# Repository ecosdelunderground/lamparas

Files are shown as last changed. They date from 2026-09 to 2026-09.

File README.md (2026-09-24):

# Ciudadela / Starlit Stag — lámpara imprimible

Del OBJ de Meshy a **tres piezas** que se montan con cinco tornillos. La silueta y
la piedra del marco son **las del OBJ original**. El nicho (escalón, corona,
pozo) está **redibujado según la Ciudadela de Jaca** (`ciudadela.py`): polígonos
limpios y simétricos, planos de verdad, nada cortado contra las facetas de Meshy.

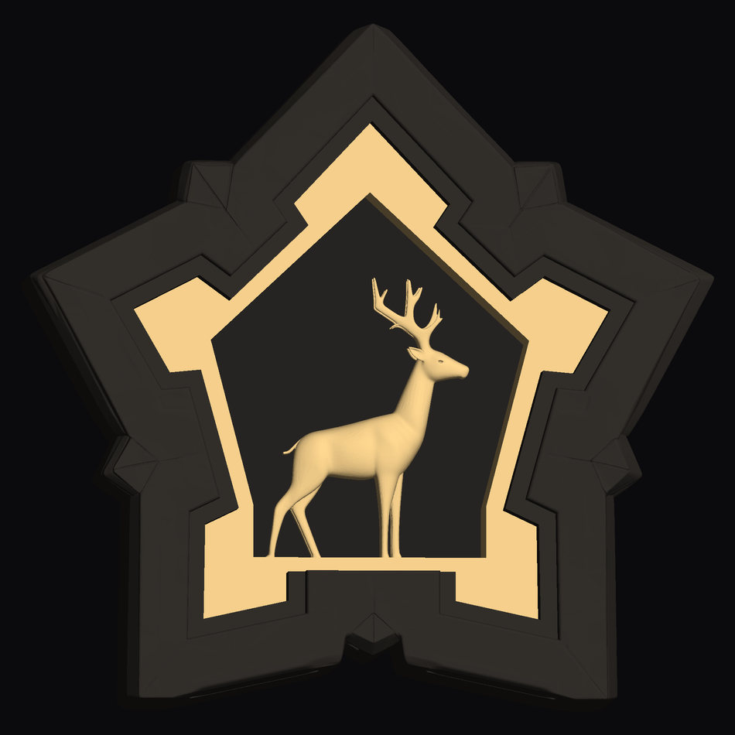
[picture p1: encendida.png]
encendida


## Las tres paredes

| pared | pieza | material |
|---|---|---|
| exterior, el marco de la estrella | `1_piedra` | opaco |
| **la iluminada**: la corona que rodea la boca del nicho | `2_luz` | **translúcido** |
| **el escalón interno** que baja hasta el fondo | `2_luz` | **translúcido** |
| la de detrás del ciervo | `3_tapa` (pedestal) | opaco |
| el ciervo, en relieve | `2_luz` | **translúcido** |

La pared iluminada es la corona plana a Z = +10,90 (**3 885 mm²**). El escalón
interno son las cinco paredes del pozo, 23,9 mm de caída. El fondo del nicho no
emite: son **13,4 mm de opaco macizo**, y va montado en la tapa.

### El trazado de la Ciudadela (`ciudadela.py`)

Simétrico respecto a X = 0, de fuera hacia dentro:

- **Marco de 17 mm constante** en todas las caras de los baluartes (silueta → W2).
- **Escalón de 5 mm constante** (W2 → borde de la corona), plano único a Z 21,34.
- Entre baluartes, cortina con orejón a cada lado; **entrantes a 100°**.
- Puntas laterales con las dos caras iguales (29,8 mm).
- **Pozo**: pentágono simétrico con los lados de abajo verticales, para
  enmarcar al ciervo; el ciervo va **4,9 mm a la derecha** para quedar centrado.
- Contorno interior: la franja de terraza junto a la pared (8 mm) se rehace a la
  altura de la terraza buena, con un **canto redondo de 1 mm** arriba de la pared.
- Rombo de la punta de abajo: **copia de la malla del rombo lateral**, llevada a
  la punta de abajo y reflejada (simétrico).
- Canto de fuera de las dos caras de abajo (en Meshy ondulaba): perfil medio
  barrido recto a lo largo de la cara.
- Todas las costuras con Meshy se cruzan en ángulo suave: sin escalón.

## Las tres piezas

| | filamento | tamaño | volumen |
|---|---|---|---|
| `1_piedra` | opaco, acabado piedra | 200 × 198 × 55 mm | 752 cm³ |
| `2_luz` | **translúcido** | 139 × 145 × 37 mm | 78 cm³ |
| `3_tapa` | opaco | 166 × 171 × 16 mm | 138 cm³ |

`2_luz` es **una sola pieza**: corona + escalón interno + ciervo + una **falda
exterior** que baja desde el borde de la corona hasta la tapa. Entre el tubo y la
falda, un **pasillo de luz de 5 mm que da la vuelta entera** al tubo (también bajo
el suelo del ciervo), sin macizos que hagan sombra; en las puntas se ensancha. Donde
no cabe bajo la corona, la falda se sale de ella hasta 1,9 mm por detrás, escondida
dentro de la piedra. La falda le da a la corona en qué apoyarse y sitúa la pieza en
el hueco.

## El ciervo

Ya no flota con un tallo por detrás. Es un **relieve de 15 mm** que sale de la
pared del fondo: se recula 10,9 mm y se queda pegado a ella, conservando su
contorno exacto y los 15 mm delanteros de su modelado original. Por detrás no
queda nada: el hueco del ciervo desemboca directamente en un agujero con su
silueta (metida 2,5 mm, así que no se ve) en el pedestal de la tapa, y ahí es
donde va su trozo de tira LED.

## Medidas

| | |
|---|---|
| Estrella | 200 × 198 mm |
| Grosor | 55,1 mm + 3 mm de tapa = **58,1 mm** |
| Nicho | 23,9 mm de profundidad |
| Fondo del nicho | **13,4 mm de opaco** |
| Relieve del ciervo | 15 mm |
| Pasillo de luz | 5 mm alrededor de todo el tubo |
| Paredes translúcidas | 2,0 mm mínimo |

## Impresión

Las tres salen **en la orientación en la que están exportadas**, cara plana abajo
y todas las cavidades abriendo hacia arriba. Piedra y tapa, **sin soportes**.
La luz, **con soportes solo debajo del ciervo**: su relieve empieza 13,4 mm por
encima de la cama (8 islas entre Z −13,0 y −3,4). Los soportes tocan el lomo
trasero, que va contra el fondo y no se ve. Lo demás de la luz se puentea solo:
la primera capa de la corona es un puente de 15,1 mm como mucho (en las puntas;
revisa los ajustes de puentes del laminador).

- Boquilla 0,4 · capa 0,2 · **3 perímetros**.
- Piedra: relleno 10–15 %. Huella de 200 × 198 mm, comprueba que te cabe.
- Luz: **10 % de giroide y 3 perímetros** (0 % dejaría la corona sin sobre qué
  apoyar las capas de arriba).
- Tapa: 15 %.

La trasera de la estrella la he **aplanado 0,5 mm** para quitarle la textura de
Meshy: agarra la primera capa y la tapa asienta plana.

## Montaje

1. Mete `2_luz` **por detrás**, empujando hacia delante hasta que la corona
   asiente en su rebaje.
2. Pega la tira LED dentro de la caja de `2_luz`, sobre la tapa, y un trozo justo
   debajo del agujero del ciervo. Pasa el cable por la muesca del espigo.
3. Atornilla `3_tapa`: **5 × M3 × 10 autorroscantes de cabeza avellanada**
   (el avellanado de 90° abre hacia la cara de fuera y la cabeza queda
   enrasada), a taladros de Ø2,7 y 8 mm de fondo. Su pedestal es el fondo del nicho y, al apretar, deja la
   pieza de luz cogida contra su rebaje: no hace falta pegamento.
4. El cable baja por el canal de la trasera y sale por la muesca de entre los dos
   pies, a ras de mesa.

Comprobado moviendo cada pieza por **todo el recorrido** de montaje (1, 2, 4, 8,
16, 30 y 50 mm), no solo en la posición final: 0 mm³ de choque.

## Ficheros

```
preparar.py      genera las tres piezas desde el OBJ (parámetros arriba del todo)
ciudadela.py     trazado del nicho (W2, escalón, pozo), fijado como diseño
verificar.py     50 comprobaciones + renders
geo.py           secciones horizontales en coordenadas mundo
render.py        rasterizador para los renders
1_piedra / 2_luz / 3_tapa   .stl y .ply
montada.3mf      las tres en su sitio, para mirarlo antes de laminar
```

## Comprobado (50/50)

- Las tres piezas cerradas, de un solo trozo, sin triángulos degenerados ni
  pellizcos (también los .stl), y sin lengüetas o rendijas de menos de 0,8 mm
  en lo construido (en la piedra rehecha solo quedan las ranuras del diseño).
- Solape entre piezas: 0,00 mm³.
- Silueta exterior intacta fuera de lo rehecho (0,019 mm); marco visto: 0 de
  1 380 puntos desviados más de 0,3 mm fuera de lo rehecho a propósito.
- Detrás del fondo del nicho: **100 % opaco**, 0 % translúcido.
- Corona: un solo plano (±0,0000 mm) y translúcida en toda su planta.
- Pared mínima: 2,0 mm en la pieza de luz, 1,16 mm en el ciervo.
- Mínimo 16,2 mm de piedra entre el pasillo de luz y el exterior.
- Recorrido de montaje completo sin choques, pieza a pieza.
- Voladizos capa a capa: puente de 4,0 mm en la piedra, 15,1 mm en la luz,
  0 en la tapa; las únicas islas son las 8 bajo el ciervo (con soporte).

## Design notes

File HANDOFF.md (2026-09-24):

# Handoff — lámpara Ciudadela / Starlit Stag

Pega esto en una sesión nueva para continuar.

---

Estoy preparando para imprimir en 3D una lámpara a partir de un OBJ de Meshy AI.
El proyecto vive en `C:\Users\sergi\Documents\claudeproject\estrella-meshy`.
Lee primero el `README.md` y `preparar.py` de esa carpeta.

**Entorno**: Python de sistema en
`C:/Users/sergi/AppData/Local/Programs/Python/Python313/python.exe`, con trimesh,
shapely, manifold3d, scipy, matplotlib, PIL, rtree. El motor de booleanas es
`manifold`. El OBJ original está en
`C:/Users/sergi/Downloads/Meshy_AI_Starlit_Stag_0923134854_generate_obj/Meshy_AI_Starlit_Stag_0923134854_generate_obj/Meshy_AI_Starlit_Stag_0923134854_generate.obj`.
No modifiques el OBJ; todo se genera desde él con `preparar.py`.

## Qué es

Estrella de 5 puntas de 200 × 198 × 58 mm con un nicho pentagonal y un ciervo
dentro. Se imprime en **tres piezas** y se monta con 5 tornillos M3:

- `1_piedra` (filamento opaco, acabado piedra): el marco de la estrella.
- `2_luz` (filamento **translúcido**): UNA sola pieza = la corona iluminada que
  rodea la boca del nicho + el escalón interno (la pared del pozo) + el ciervo en
  relieve + una **falda exterior** oculta dentro de la piedra que hace que la
  pieza se imprima sin soportes y forma la caja donde va la tira LED.
- `3_tapa` (opaco): cierra por detrás, lleva los tornillos y el canal del cable, y
  **lleva montado el fondo del nicho** (la pared de detrás del ciervo) como un
  pedestal de 13,4 mm.

## La regla de la luz (esto costó cinco rondas, no te la saltes)

Hay **tres paredes** en el nicho. Solo se encienden dos de ellas y el ciervo:

| pared | pieza | ¿emite? |
|---|---|---|
| marco exterior de la estrella | `1_piedra` | **NO** |
| **la corona iluminada** (la franja plana a Z ≈ +11 que rodea la boca, 7–9 mm de ancho vista de frente) | `2_luz` | **SÍ** |
| **el escalón interno** (las paredes del pozo, 24 mm de caída) | `2_luz` | **SÍ** |
| el fondo, detrás del ciervo | pedestal de `3_tapa` | **NO** |
| el ciervo | `2_luz` | **SÍ** |

El ciervo es un **relieve de 15 mm** pegado al fondo: se recula 10,9 mm respecto
al OBJ y se corta en el plano del fondo. No lleva tallo ni hueco por detrás; la
luz le entra por un agujero con su silueta (metida 2,5 mm, así no se ve) en el
pedestal de la tapa. Las pezuñas se hunden 4 mm en el suelo del pozo para que el
relieve quede soldado a la pieza y no salga suelto.

## Cotas y decisiones ya cerradas

- Escala: 200 mm de ancho → 105,2085 mm por unidad del OBJ.
- Planos: trasera aplanada `Z=-26,41` · fondo del nicho `Z=-12,99` · cara de la
  corona `Z=+10,90` · junta corona/tubo `Z=+7,40` · frente `Z=+28,69`.
- Pared translúcida 2,0 mm, falda 2,0 mm, holgura única 0,2 mm, corona 3,5 mm.
- Orientación de impresión = la de exportación: cara plana en la cama, cavidades
  hacia arriba, **sin soportes**.
- La pieza `2_luz` entra **por detrás** (el marco se mete hacia dentro por abajo y
  no cabe por delante). La tapa también por detrás. Verificado desplazando cada
  pieza 1/2/4/8/16/30/50 mm e intersecando, no solo en la posición final.
- La trasera de la estrella se aplana 0,5 mm para quitarle la textura de Meshy.

## Dónde estoy ahora mismo (a medias)

Sergi vio las piezas en el laminador y **rechazó las costuras**: bordes en sierra,
lengüetas finas y ondulaciones, porque yo estaba cortando todas las caras de
encaje contra la malla facetada de Meshy. Medido: la cara de la corona iba de
Z +6,25 a +20,80 en vez de ser un plano, y las piezas llevaban 4 324 y 12 563
triángulos por debajo de 0,001 mm².

Acordamos con él: **nada que encaje se corta contra la malla**. Todo sale de dos
polígonos limpios (lados rectos, esquinas vivas) y dos planos de verdad. Eligió
expresamente «contornos limpios sin tocar la forma», **no** simetrizar (medí que
simetrizar movería el pozo 6,4 mm y la estrella 7,7 mm, y se lo dije).

`preparar.py` ya está reescrito con ese criterio y **corre entero**. Última salida:

```
POZO:   1467 vertices -> 16 lados rectos, desviacion max 1.03 mm, area 7171 mm2
CORONA: 6419 vertices -> 37 lados rectos, area 3398 mm2, ancho medio 7.5 mm
(la falda pide 5822 mm2 por fuera del escalon del marco)
piedra: pulido 235042 -> 235042 caras, 484 astillas, cerrada=True   754.8 cm3
luz:    la limpieza abria la malla, se deja como estaba              80.4 cm3
tapa:   la limpieza abria la malla, se deja como estaba             137.5 cm3
```

### Lo que queda por hacer

1. **`verificar.py` está desactualizado y no arranca**: espera el `cotas.npy` y el
   `contornos.wkt` del diseño anterior. Ahora `preparar.py` escribe
   `cotas = [S, Z_TRASERA, Z_SUELO, Z_CORONA, Z_JUNTA, Z_FRENTE, OFF_LUZ,
   OFF_PIEDRA, TAPA_ESP, CIERVO_RELIEVE, HOLGURA, FALDA]` y
   `contornos.wkt = SIL_CIERVO, POZO, AEX, CORONA`. Hay que adaptarlo y volver a
   pasar las comprobaciones (la versión anterior sacaba 24/24).
2. **`pulir()` no consigue limpiar `2_luz` ni `3_tapa`**: al fusionar vértices la
   malla se abre, así que se queda como estaba. Hay que resolverlo de verdad
   (fusión por distancia con tolerancia, o rehacer esas piezas para que no salgan
   astillas de las booleanas). Es justo lo que Sergi quiere arreglado.
3. **Verificar que la falda no muerde el escalón visible del marco**: el log dice
   que pide 5 822 mm² por fuera de la corona. Hay que mirarlo en render y, si se
   come marco visible, estrechar la falda o recortarla ahí.
4. **Renderizar y enseñárselo**: no he mirado todavía la versión limpia. Usa
   `render.py` (rasterizador propio) y compara con la versión anterior.
5. Actualizar el `README.md` con las cotas nuevas cuando esté cerrado.

## Sesión del 24-09 (nube): estado

El OBJ está en el repo como `meshy.obj`; `preparar.py` y `verificar.py` lo
buscan ahí primero. Piezas regeneradas. `verificar.py`: **40/43**.

Decisiones de Sergi (24-09):
- **Falda, opción B**: se deja la franja de corona que recorta el marco (bloque
  de abajo y esquina de la roca) para verlo impreso. Si no gusta, opción A:
  sin corona donde el original no la tiene, placa escondida bajo el marco.
- **Soportes solo bajo el ciervo** en la pieza de luz (su relieve empieza en el
  aire en la orientación de impresión). Descartado el apoyo oculto en el pedestal.

Hecho:
- `pulir()`: para si la booleana deja pellizcos (fallo de diseño) y colapsa
  astillas con `Manifold.simplify` (0,001 mm; la luz 0,01 mm, que cierra los
  pliegues de vacío < 0,01 mm que deja la erosión dentro del ciervo).
- Tapa: el avellanado estaba al revés y su cono tocaba el taladro en un círculo.
- Luz: boca trasera del ciervo dentro de su base real (el prisma de la silueta
  cortaba el lomo casi horizontal y pellizcaba); pezuñas prolongadas en recto
  hasta media pared del tubo (antes: muñones fantasma y asomaban a la caja).
- POZO: la envolvente se muestrea solo hasta la junta. Antes llegaba a Z +9,4 y
  metía en el pozo un rellano de la corona (esquina de la roca, Z ≈ +9), creando
  un pocillo iluminado de 24 mm que el original no tiene. Desvío al original:
  19,4 → 1,74 mm.
- `verificar.py`: malla limpia, regla de la luz, falda, sección 4 separando lo
  aceptado, recorrido fino, e islas en el aire (la de antes no las veía).

- Malla perfecta: `sanear()` en `pulir()` quita los triángulos degenerados
  (colapsa lados < 0,01 mm con condición de enlace, voltea agujas) y exige 0.
  `verificar.py` comprueba también los .stl.
- `render.py` con z-buffer: el algoritmo del pintor sacaba esquirlas falsas.
- Anomalías que Sergi vio en el laminador (24-09), arregladas:
  - Picos en esquinas del pozo y del borde de la corona (dientes que deja
    `simplify`): `sin_dientes()` quita zigzags y rehace esquinas mordidas.
  - Rendija de 0,4 mm entre tubo y falda en toda la altura: la caja del LED es
    ahora el hueco sin zonas de menos de 1,5 mm; lo demás se maciza (caja: 17
    cm² útiles; las rendijas no servían para el LED).
  - Espigo y agujero del pedestal sin partes de menos de 1,2 mm.
  - Hueco del ciervo solo donde la silueta pasa de 8 mm: en patas y cuernas
    dejaba láminas de vacío que se verían al trasluz.
  - Pezuñas: cada una baja al suelo con su forma (envolvente convexa de su
    último mm); antes quedaba una rendija de 0,4–0,6 mm bajo las patas.
- `CORONA_BORDE`: probado 'fuera' (la corona hasta la pared del escalón) y
  descartado: el corte recto cruza en rasante la pared texturada y deja costura
  en sierra. Se queda 'dentro'.
- `verificar.py`: contornos sin dientes y barrido de lengüetas/rendijas < 0,8 mm
  en lo construido (tapa entera, luz fuera del ciervo). **49/50**.

- **Borde de la corona por el canto (`CORONA_BORDE = 'canto'`)**, a petición de
  Sergi (24-09): las paredes corona→escalón de Meshy eran rampas con nervaduras
  y cantos dentados. El borde de la corona se traza ahora por el canto de arriba
  de esa pared (Z_ESCALON − 0,5, sacado 0,4 mm sobre la cara plana): el rebaje
  se lleva la rampa entera y deja una pared vertical lisa cuyo canto corta en
  perpendicular la cara plana del escalón (Z 21,19). La corona pasa a 4 544 mm²
  (10,4 mm de ancho medio). Probado antes 'fuera' (costura en sierra) y
  'dentro' (tira de piedra); ver comparación en la conversación.
- Eje de simetría medido: X = 0 sin giro; alturas de terrazas simétricas
  (mediana 0,08 mm); las paredes difieren unos mm de un lado a otro.

- Corrección de Sergi (24-09, capturas del laminador): en los dos valles de
  arriba la cara del escalón de Meshy tiene hondonadas (Z 19–20 en vez de 21,2).
  El borde por el canto se metía en ellas (derecha: se comía el escalón;
  izquierda: dos planos). Ahora: el borde se toma a media pared (Z 16,0) y se
  endereza con 2 mm; y la cara del escalón se RELLENA hasta un plano único
  (Z_ESCALON + 0,15 = 21,34) en 8 mm por fuera del borde, antes de cortar el
  rebaje. Hondonadas y restos de rampa quedan enterrados; donde la superficie
  ya está más alta no cambia. Borde de la corona: 29 lados, valles simétricos.
- `TOL_POZO` 1,2 → 0,9: pozo de 11 lados, 99 % de las paredes a < 1,05 mm del
  original.

`verificar.py`: **50/50**.

Queda de Meshy sin tocar: la pata delantera modelada como una tabla plana.

## Rediseño Ciudadela (24-09, aprobado por Sergi: «Ahora SÍ»)

El nicho ya no sigue las paredes de Meshy: se traza según la Ciudadela de Jaca
(el logo de su web), como interpretación artística pero simétrica y con ángulos
coherentes. Todo el trazado está en `ciudadela.py`, fijado como diseño (no se
recalcula desde el OBJ); `preparar.py` lo usa con `CORONA_BORDE = 'ciudadela'`
(los modos 'dentro', 'fuera' y 'canto' siguen ahí para comparar).

- `W2` (escalón → terraza): cada cara de baluarte a **17 mm** de la silueta
  simetrizada; cortinas con orejones; entrantes a **100°**; puntas laterales con
  sus dos caras iguales (29,8 mm).
- `AEX` (borde de la corona) = W2 metido **5 mm** (escalón constante). En la
  puerta de abajo no hay escalón por arriba.
- `POZO`: pentágono simétrico dibujado por Sergi, lados de abajo verticales.
  El ciervo se aísla con el pozo de Meshy (`POZO_MESHY`) y luego se desplaza
  `CIERVO_DX = 4,9` mm a la derecha para quedar centrado.
- Piedra: el escalón es un prisma plano a `Z_RELLENO = 21,34`; la terraza de
  8 mm por fuera se alisa con un campo de alturas (nivel del píxel de terraza
  más cercano, filtro de mediana); el valle de la punta de abajo es copia del
  valle lateral derecho girada 73° (+0,22 mm), aplicada solo donde sube, para
  que su rombo quede delante como los demás.
- Luz: la caja del LED lleva un núcleo macizo en el centro (54 mm²) para que el
  puente de la corona no pase de 12,9 mm.
- `cotas.npy` tiene 14 valores (añade `Z_RELLENO` y `RELLENO_ANCHO = 13`).
- `verificar.py`: la silueta y el marco se comparan fuera de lo rehecho
  (`AEX.buffer(RELLENO_ANCHO + 0,3)` y la puerta de abajo); el pozo se informa
  pero no se exige (está rediseñado).

Segunda ronda (Sergi, 24-09: «subir la altura de lo nuevo y un canto redondeado»):
- (a) Terraza junto a W2: nivel = terraza buena más cercana (a más de
  `TERRAZA_LIMPIA` de la pared y sin hundirse respecto a su entorno), suavizado
  donde se extrapola; canto redondo `CANTO_R` = 1 mm.
- (b) Rombo de abajo: malla real de media punta lateral (`ROMBO_LAT` ->
  `ROMBO_ABAJO`, afín), cosida por X = 0 (sin booleana: pellizcaba), trasera
  macizada 1,6 mm (ranuras de Meshy en la primera capa).
- (c) Caras de abajo: pared recta ajustada y canto con el perfil medio, en rejilla
  alineada con la cara (un campo de alturas daba dientes en el canto empinado).
- Costuras: nunca superficie contra superficie de refilón (pellizcos) ni escalón
  (se ve como una línea). `a_costura()`: lo nuevo pasa de `COSTURA` por encima a
  2x por debajo en `RAMPA` mm y cruza a Meshy en ángulo.
- `contornos.wkt` lleva una 5ª línea, REHECHO; `verificar.py` compara fuera de
  ella y revisa láminas/rendijas en la piedra rehecha (descontando las ranuras
  del diseño: las de Meshy, las del rombo copiado y las esquinas del canto).

`verificar.py`: **50/50**. Piedra 752 cm³, luz 88 cm³, tapa 136 cm³, corona
3 885 mm², caja del LED 39 cm² × 34 mm.

Queda de Meshy sin tocar:
- la pata delantera modelada como una tabla plana;
- la textura de piedra de las paredes del marco (de la terraza a la cara de
  delante) y de los rombos de las puntas. Es la piedra original; si Sergi la
  quiere lisa, es el siguiente paso.

## Pasillo de luz (24-09, aprobado: «eso es»)

Sergi: toda la pieza de luz, por detrás, tiene que ser un corredor de luz; nada
de paredes o macizos dentro que hagan sombra. Hecho:
- Sin núcleos macizos en las puntas (`CAJA_MAX` eliminado).
- `LUZ_EXT` = corona ∪ `off(POZO, PARED + PASILLO + FALDA)`: pasillo de
  `PASILLO` = 5 mm alrededor de todo el tubo, también bajo el suelo del ciervo.
  Donde no cabe bajo la corona, la falda se sale hasta 1,9 mm por detrás (bajo la
  junta, tapada por la piedra del escalón); ahí el pasillo lleva un techo de 1,5 mm.
- Hueco de la piedra, tapa, espigo, tornillos y canal del cable siguen a `LUZ_EXT`.
- `verificar.py`: «la luz no toca el marco» se mira por encima de la junta; el
  puente de la corona en las puntas (15,1 mm) se acepta hasta 16 mm.

`verificar.py`: **50/50**.

## Cómo trabaja Sergi (importante)

- La parte estética la lleva él y te la marca sobre fotos y renders. Tu papel es
  la ingeniería de fabricación: booleanas, espesores, voladizos, encajes y
  verificación numérica. No le propongas conceptos propios.
- **Antes de un cambio grande, confírmale lo que has entendido** y enséñale un
  esquema o un render. Te lo ha pedido explícitamente dos veces.
- Mide y da números, no impresiones. Verifica el **recorrido entero** de montaje,
  no solo la posición final.
- `limpiar()` aborta si una booleana desprende algo de más de 50 mm³: eso no es
  una miga, es una pieza que ha quedado aislada. No subas ese umbral para que
  pase; arregla el diseño.
- Hay notas de la serie de lámparas en la memoria del proyecto
  (`project-lamparas-3d`), con las lecciones de los modelos anteriores.

Empieza por leer `preparar.py` y ejecutarlo para ver el estado, y sigue por el
punto 1.

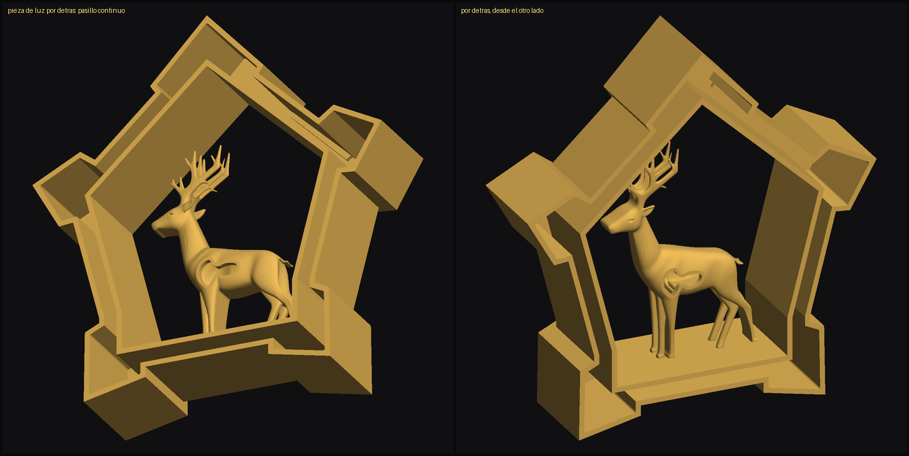
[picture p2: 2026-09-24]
luz_pasillo.png

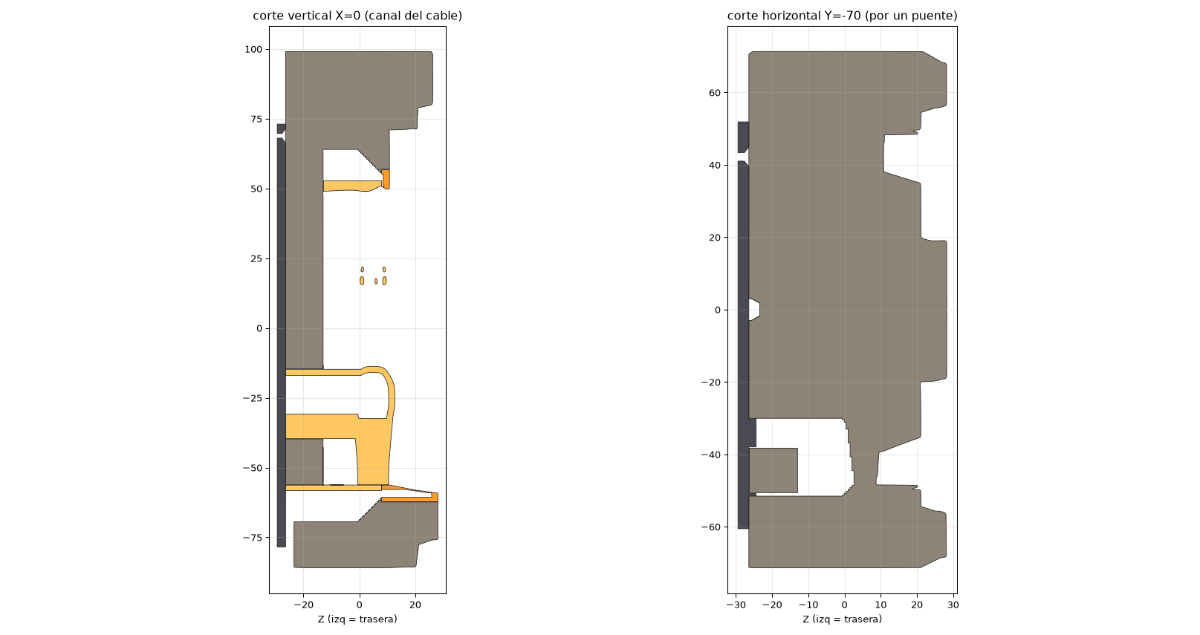
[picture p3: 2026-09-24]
cable.png

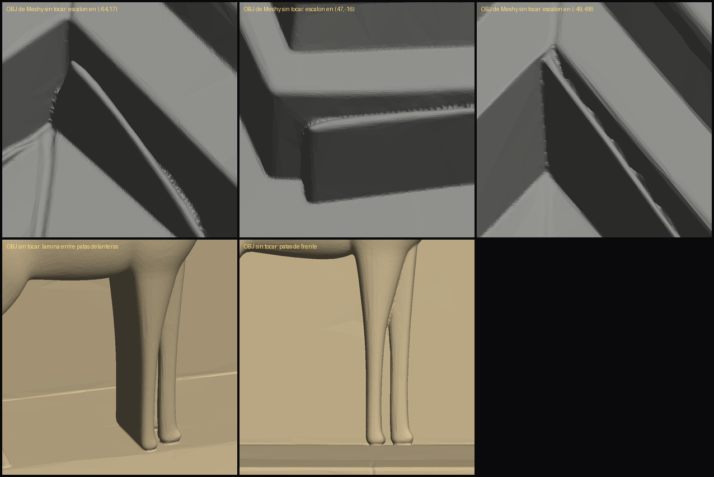
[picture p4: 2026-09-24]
defectos_meshy.png

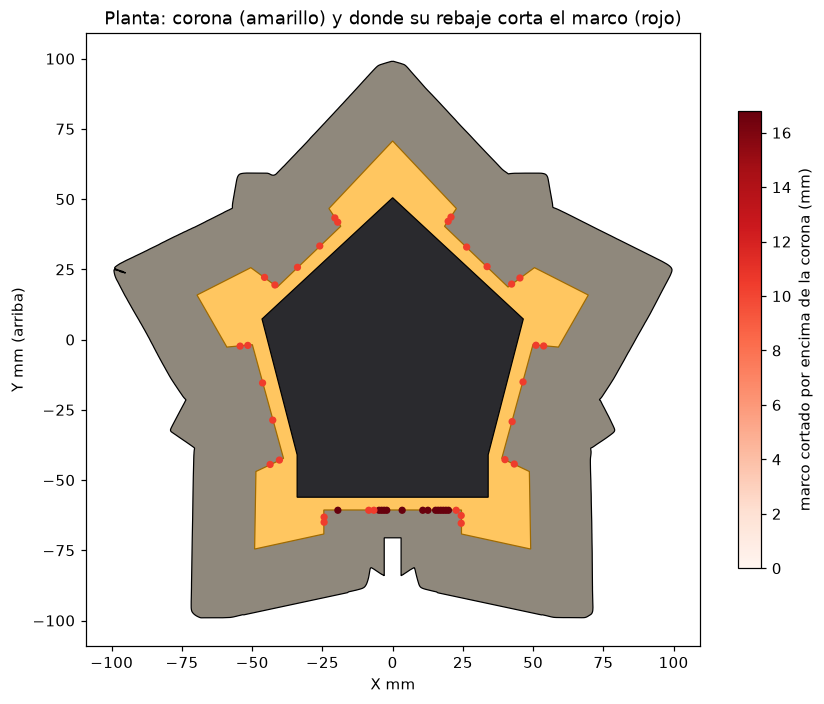
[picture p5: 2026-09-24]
falda_marco.png

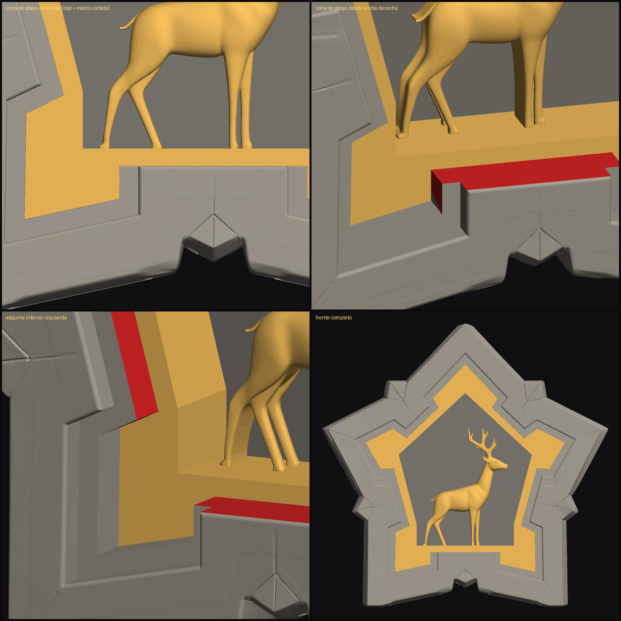
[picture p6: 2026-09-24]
falda_zoom.png

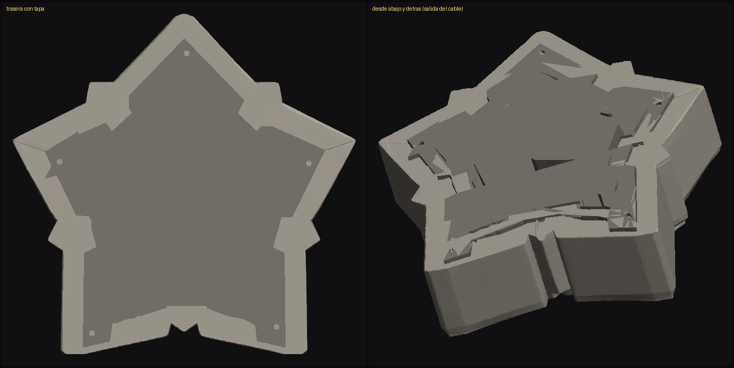
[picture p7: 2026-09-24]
trasera.png

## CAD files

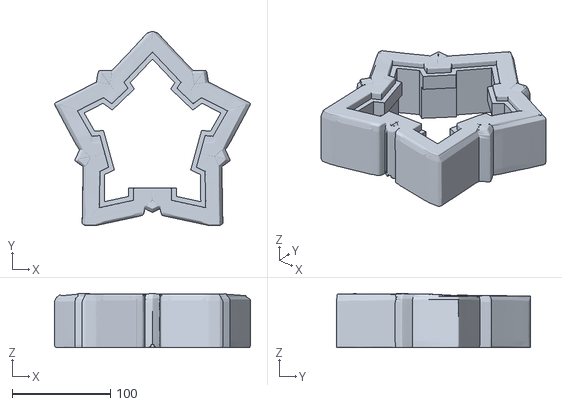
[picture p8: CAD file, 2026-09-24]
1_piedra.stl
200.0 x 198.1 x 55.2

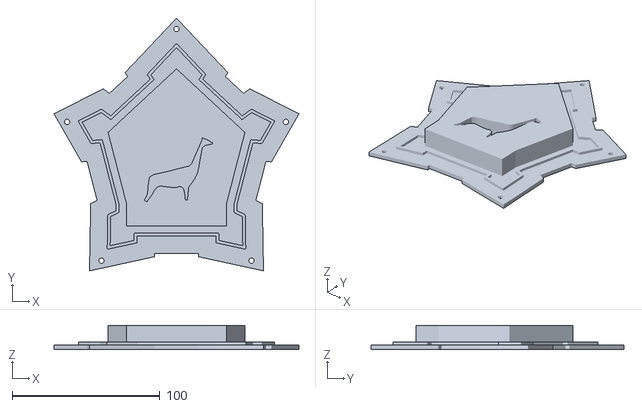
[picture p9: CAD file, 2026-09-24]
3_tapa.stl
165.7 x 170.9 x 16.4

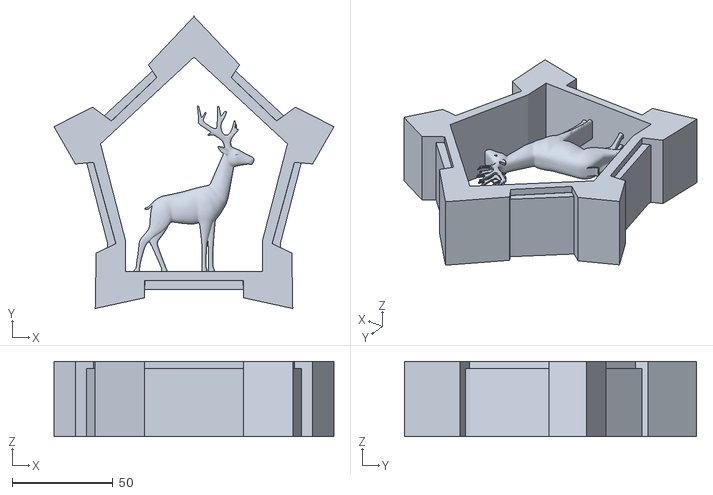
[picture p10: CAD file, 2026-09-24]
2_luz.stl
139.3 x 145.2 x 37.3

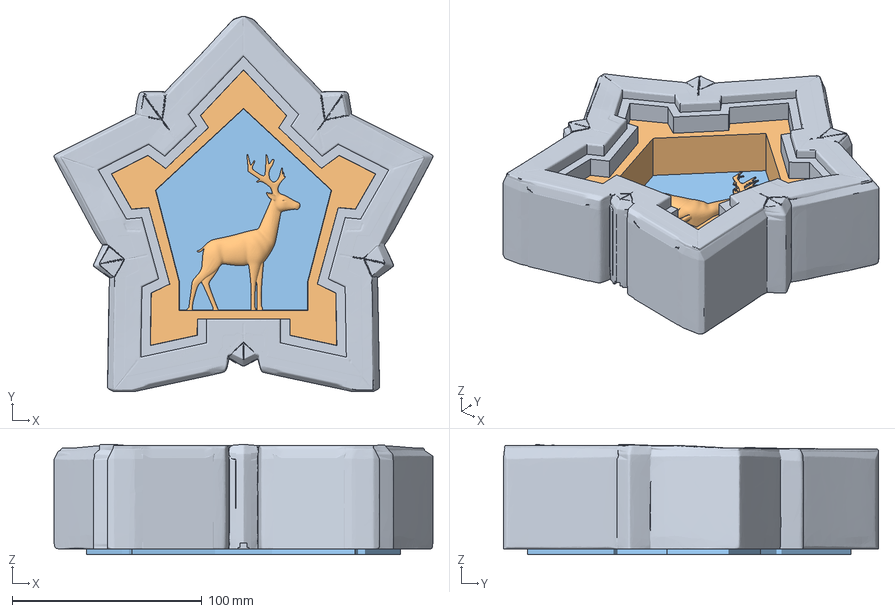
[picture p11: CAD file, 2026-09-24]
montada.3mf
200.0 x 198.1 x 58.2 mm
geometry_0
geometry_1
geometry_2

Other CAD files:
1_piedra.ply
2_luz.ply
3_tapa.ply

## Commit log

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2026-09-24 Luz sin pellizcos: boca trasera en la base real y pezunas rectas
    - El vaciado del ciervo ya no usa el prisma de la silueta (su tapa a
    Z_SUELO+0,2 cortaba el lomo casi horizontal y pellizcaba la malla):
    boca trasera dentro de la base real del relieve, con 1,2 mm de pared.
    - Pezunas: se prolonga su planta en linea recta hasta media pared del
    tubo (antes la copia desplazada dejaba munones a la vista).
    - La luz se pule a 0,01 mm (cierra pliegues de vacio < 0,01 mm).
    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
    [1_piedra.ply, 1_piedra.stl, 2_luz.ply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]
2026-09-24 Pozo sin pocillo en la esquina, verificacion completa con el original
    - POZO: la envolvente se muestrea hasta la junta; antes metia en el pozo
    un rellano de la corona (Z~+9) y creaba un pocillo de 24 mm que el
    original no tiene. Desvio al original: 19,4 -> 1,74 mm.
    - verificar.py: decisiones de Sergi (falda opcion B aceptada; soportes
    solo bajo el ciervo), deteccion de islas en el aire, silueta y pozo
    separando lo aceptado, area del corte de la falda por plano. 40/43.
    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
    [1_piedra.ply, 1_piedra.stl, 2_luz.ply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]
2026-09-24 Malla sin degenerados y render con z-buffer
    - pulir(): sanear() voltea agujas y colapsa aristas < 0,001 mm (solo si
    no pellizca); exige 0 triangulos degenerados. Piedra 20 -> 0, luz
    131 -> 0. Volumen: 0,00000 mm3 de diferencia.
    - render.py con z-buffer (numba si esta, si no numpy): el pintor
    dibujaba caras de detras encima y salian esquirlas que no existen.
    - verificar.py comprueba tambien los .stl. 45/46.
    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
    [1_piedra.ply, 1_piedra.stl, 2_luz.ply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]
2026-09-24 Sin dientes, rendijas ni lenguetas en lo construido
    - sin_dientes(): quita zigzags y rehace esquinas mordidas del pozo y del
    borde de la corona (los picos que se veian en el laminador).
    - Caja del LED sin rendijas: tubo y falda se macizan donde quedaban a
    menos de 1,5 mm (habia una ranura de 0,4 mm en toda la altura).
    - Espigo y agujero del pedestal sin partes de menos de 1,2 mm.
    - Hueco del ciervo solo en cuerpo, cuello y cabeza (en patas dejaba
    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
    [1_piedra.ply, 1_piedra.stl, 2_luz.ply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]
2026-09-24 Corona hasta el canto del escalon: paredes lisas sin nervaduras de Meshy
    - CORONA_BORDE = 'canto': el borde de la corona se traza por el canto de
    arriba de la pared corona->escalon. El rebaje se lleva la rampa de Meshy
    (nervaduras, cantos dentados) y deja una pared vertical lisa cuyo canto
    corta la cara plana del escalon en perpendicular.
    - verificar.py: la comparacion con el original mide las paredes del pozo;
    corona, pared nueva y falda son rehechas a proposito. 50/50.
    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
    [1_piedra.ply, 1_piedra.stl, 2_luz.ply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]
2026-09-24 Escalon allanado: borde a media pared y cara del escalon en un solo plano
    - En los valles de arriba la cara del escalon de Meshy tiene hondonadas;
    el borde por el canto se metia en ellas (se comia el escalon a la
    derecha, dejaba dos planos a la izquierda).
    - El borde de la corona se toma a media pared y se endereza con 2 mm;
    la cara del escalon se rellena hasta un plano unico (Z 21,34) en 8 mm
    por fuera del borde. Valles simetricos, 29 lados rectos.
    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
    [1_piedra.ply, 1_piedra.stl, 2_luz.ply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]
2026-09-24 Nicho redibujado segun la Ciudadela de Jaca
    - ciudadela.py: trazado simetrico del escalon (marco 17 mm constante,
    escalon 5 mm, entrantes a 100 grados, puntas laterales iguales) y pozo
    pentagonal dibujado por Sergi; ciervo 4,9 mm a la derecha.
    - preparar.py: modo CORONA_BORDE = 'ciudadela'. Escalon plano en un solo
    prisma, terraza alisada con campo de alturas, valle de la punta de abajo
    copiado del lateral para que su rombo quede delante. Nucleo macizo en la
    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
    [1_piedra.ply, 1_piedra.stl, 2_luz.ply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]
2026-09-24 WIP marco: terraza con canto redondo, rombo de abajo copiado, canto de abajo barrido
    - Terraza junto a la pared escalon->terraza rehecha a la altura de la
    terraza buena, canto redondo R1; costuras con Meshy en angulo (sin
    escalon ni pellizcos).
    - Rombo de la punta de abajo: copia de la malla de media punta lateral
    (afin + espejo, cosido en X=0).
    - Canto de las dos caras de abajo: perfil medio barrido en rejilla
    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
    [1_piedra.ply, 1_piedra.stl, montada.3mf]
2026-09-24 Marco rehecho: canto redondo, rombo de abajo y canto de abajo limpios; 50/50
    - Terraza junto a la pared suavizada donde se extrapola (sin muescas en
    los orejones); trasera del rombo copiado macizada en su primer 1,6 mm.
    - Piedra pulida a 5 micras (racimos de vertices en las costuras).
    - verificar.py: laminas/rendijas en la piedra rehecha, descontando las
    ranuras del diseno y exigiendo que sigan en el corte de al lado.
    - README y HANDOFF al dia.
    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
    [1_piedra.ply, 1_piedra.stl, montada.3mf]
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
